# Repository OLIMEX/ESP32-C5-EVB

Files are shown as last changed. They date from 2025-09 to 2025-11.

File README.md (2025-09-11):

# ESP32-C5-EVB
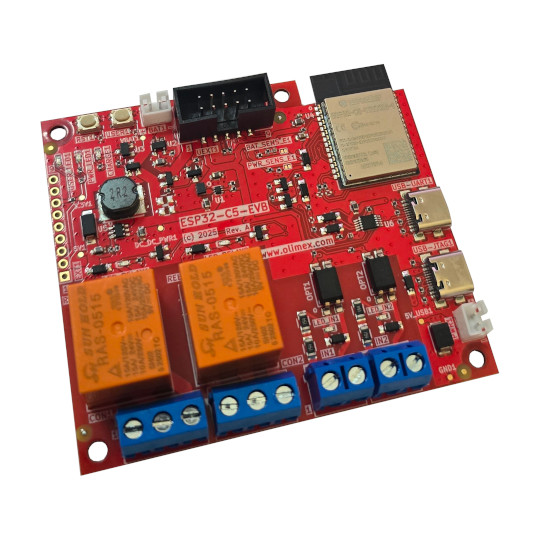
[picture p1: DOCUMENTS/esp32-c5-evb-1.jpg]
esp32-c5-evb-1


Development board for dual band 2.4G and 5Ghz WiFi 6, Bluetooth 5 LE, Zigbee, Thread, Matter development board with Relays, optoisolated inputs and LiPo battery UPS

https://www.olimex.com/Products/IoT/ESP32-C5/ESP32-C5-EVB/open-source-hardware

## Licensee
* Hardware is released under CERN Open Hardware Licence Version 2 - Strongly Reciprocal
* SOFTWARE is released under MIT Licensee
* Documentation is released under CC BY-SA 4.0

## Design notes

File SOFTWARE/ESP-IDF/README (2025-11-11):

# esp32-c5-evb-blinking-LED - esp-idf project
# After power-on the user led flashes 3 times, then blinks every second

#
# How to build the project:
#

# 1. Download esp-idf master branch or tag v5.5.1 (this project has been built with v5.5.1 tag)

git clone https://github.com/espressif/esp-idf.git

# OR

git clone https://github.com/espressif/esp-idf.git -b "v5.5.1"

# 2. Install esp-idf (do this one time only)
# 2.1 Go to esp-idf dir:

cd esp-idf

# 2.2 Run installation script. This will download and install all dependencies

./install.sh

# 3. Export esp-idf to PATH (you must do this every time, when you open terminal)
# 3.1 go to the esp-idf path:

cd PATH_TO_ESP-IDF/esp-idf

# 3.2 Execute the following command as it is, including the . symbol
. ./export.sh

# 3.3 go to the project directory
cd PATH/esp32-c5-evb-blinking-LED

# 4. Set target to esp32-c5 (one time only)

idf.py set-target esp32c5

# OPTIONAL: Change  sdkconfig  settings

idf.py menuconfig

# Build:

idf.py build

# Flash (change PORT with the actual port, related to ESP32-C5-EVB)
idf.py flash -p PORT

If everything is done after uploading the project, the led will flash 3 times, then blink every second.

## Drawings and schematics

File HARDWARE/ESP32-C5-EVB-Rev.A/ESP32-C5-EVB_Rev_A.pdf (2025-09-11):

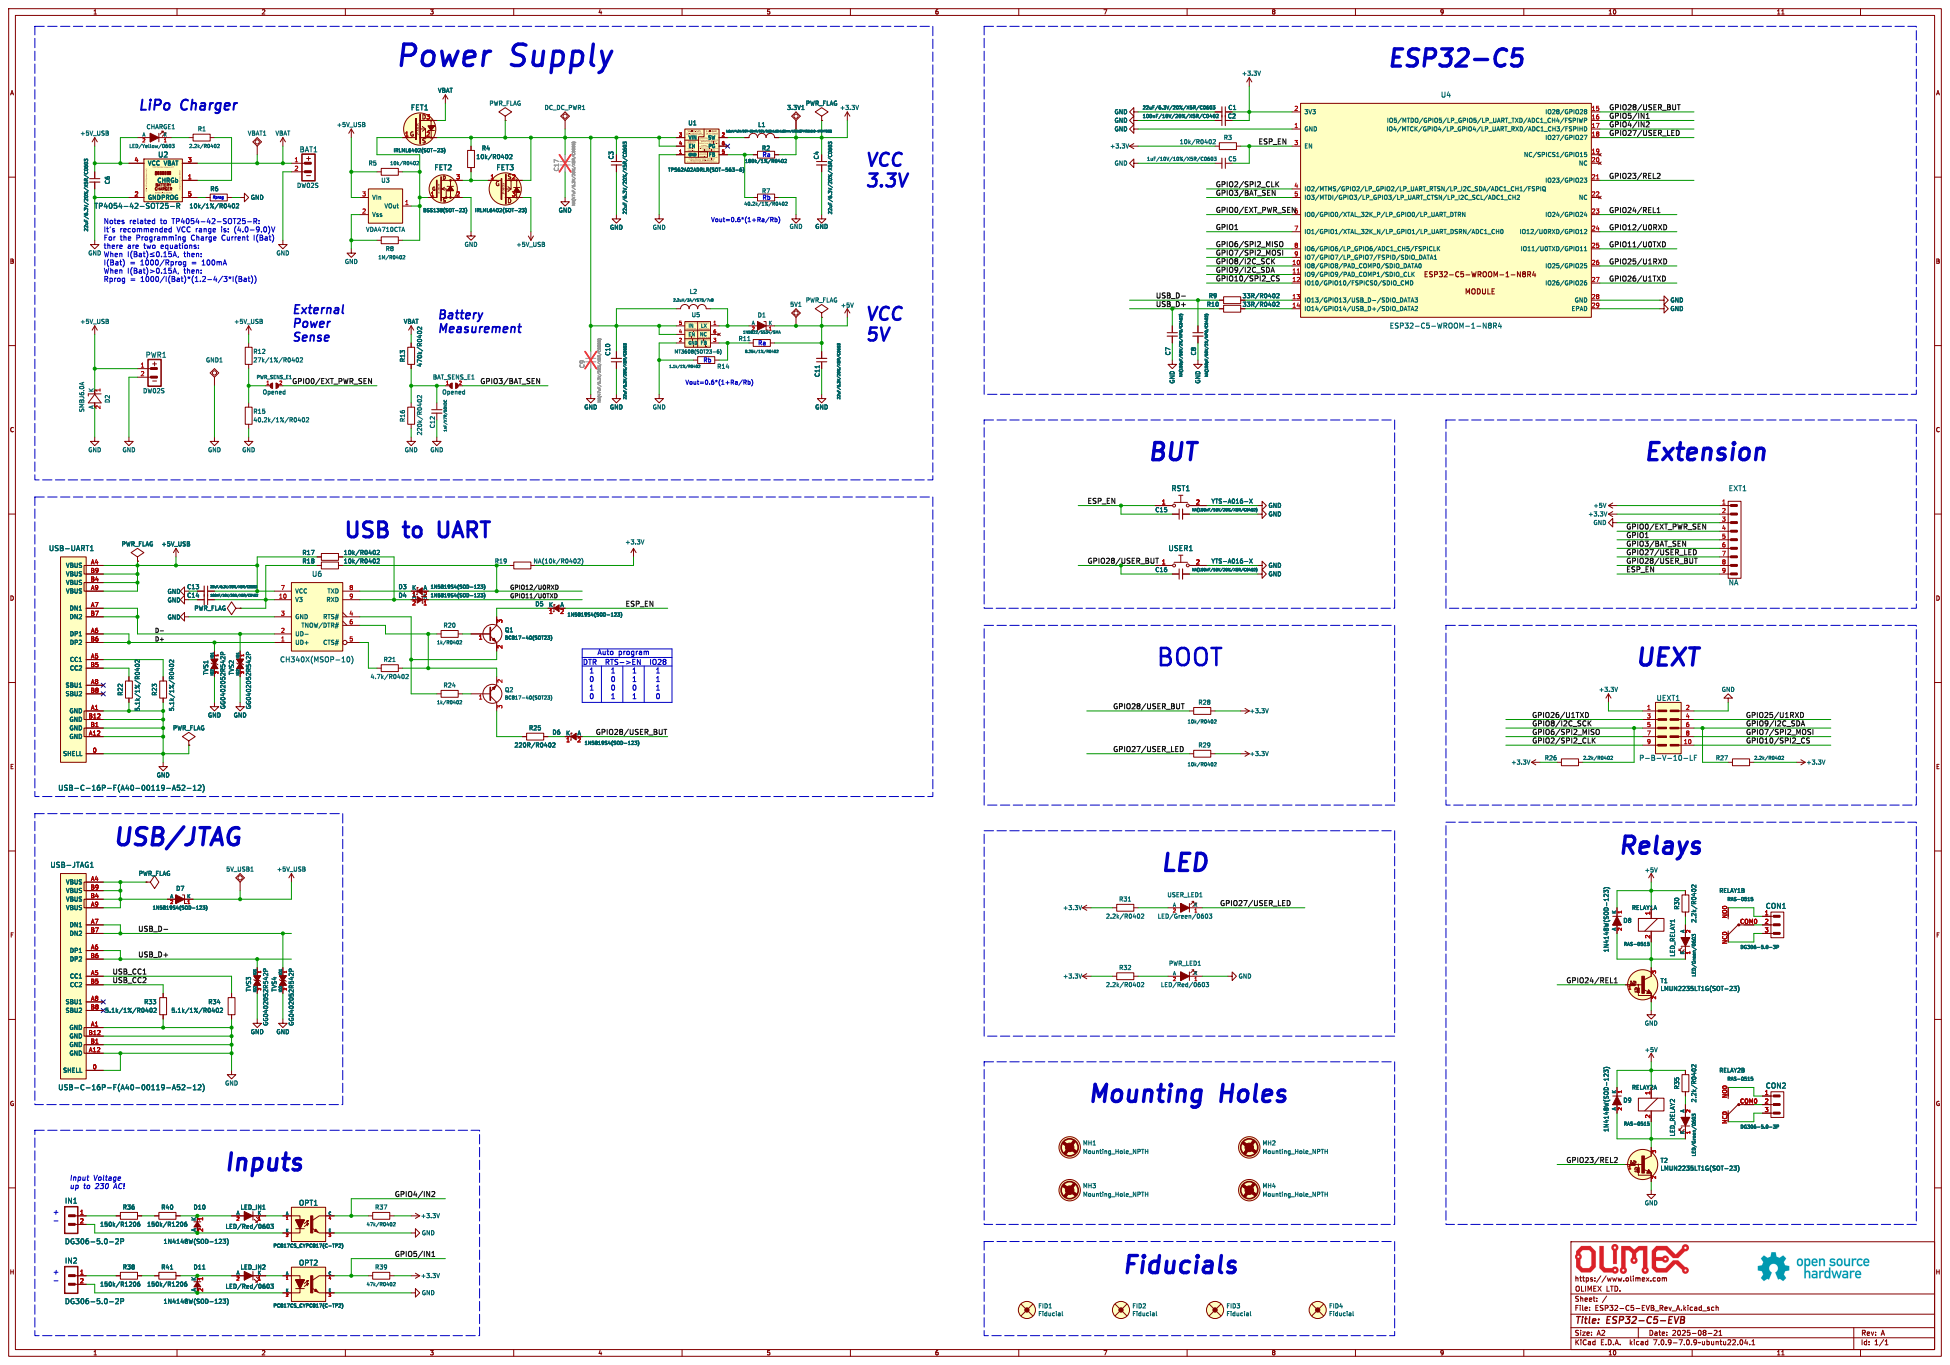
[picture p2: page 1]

In casea loweroutputrippleisdesired,higheroutputcapacitancecanhelpreducetheripple. Lx=1.0uH

Donotfloat. Enablecontrol. FB Input Current,I(FB)=100nA(max) FeedbackReferenceVoltage,V(REF)=0.6V
Rb mustnotbehigherthanþÿ100k© toprovideacceptablenoisesensitivity. ShutdownCurrentI(SHDN)=0.01-2uA

Cout=(10~22)uF/6.3V/X5Rþÿ(Vout"e1.8V). 22uFRecommended! Cout=22uF/6.3V/X5Rþÿ(1.2V"dVout<1.8V) Cout=44uF/6.3V/X5Rþÿ(0.6V"dVout<1.2V) DCR<50mR

Notes related to TP4054-42-SOT25-R:
there are two equations: When þÿI(Bat)"d0.15A, then:

Vout=0.6*(1+Rc/Rd) LX 1 GND
Current(Shutdown)=1uA(Max) FB InputBiasCurrent=-50nA(min) FB Voltage=0.6V(Typical) OperatingInputVoltage
QuiescentCurrent(PFM)=200uA(Max) QuiescentCurrent(PWM)=2.2mA(Max) RecommendedInductorvalues:up to 22uH.

because of its low forwardvoltagedropandfast reversesrecovery. V(ENH)=1.5V(Min)

V(ENL)=0.4V(Max) Vin=(2-24)VDC

The inductorshouldhavelow corelossat 1.2MHz andlow DCR for betterefficiency. RecommendedInput/OutputCapacitors: 22uF/X5R(X7R). Schottkydiodeis a goodchoicefor MT3608

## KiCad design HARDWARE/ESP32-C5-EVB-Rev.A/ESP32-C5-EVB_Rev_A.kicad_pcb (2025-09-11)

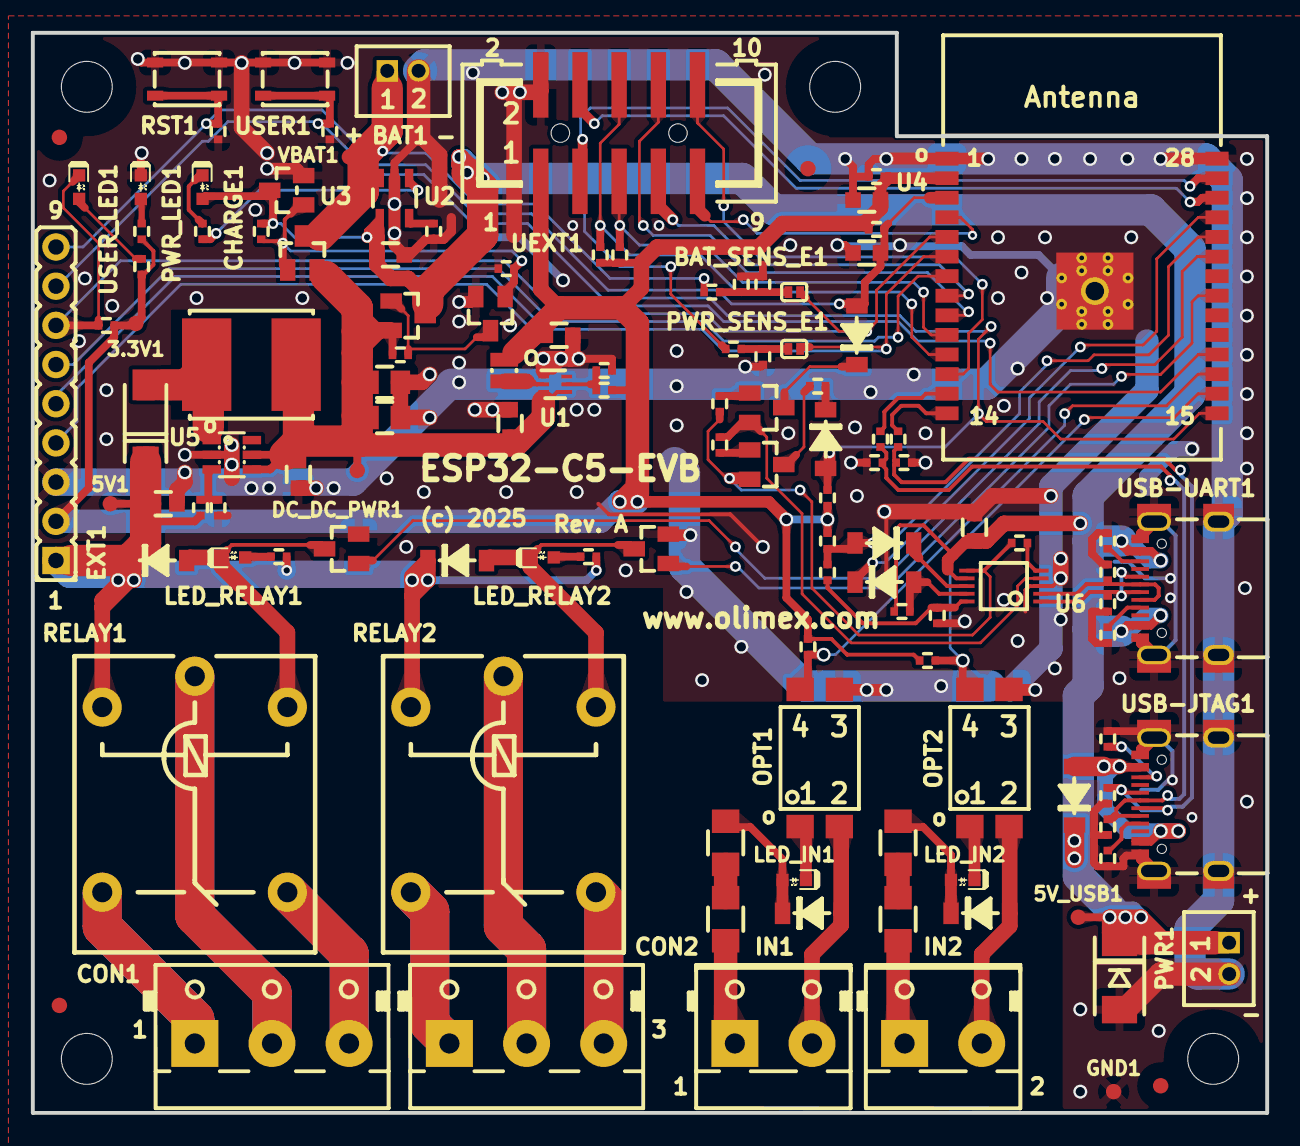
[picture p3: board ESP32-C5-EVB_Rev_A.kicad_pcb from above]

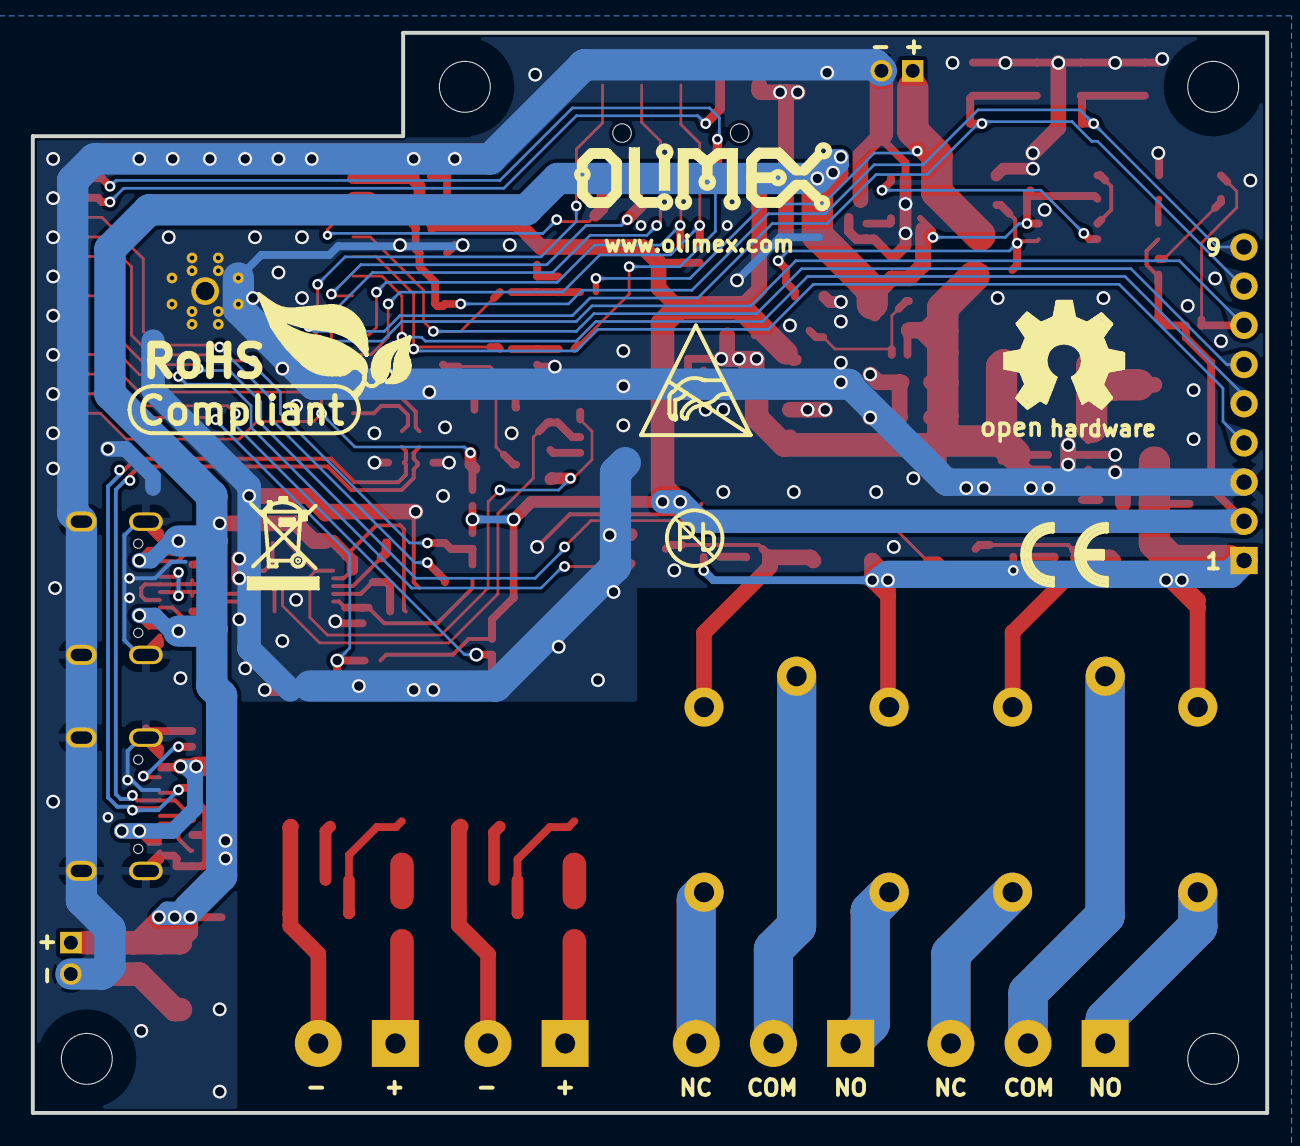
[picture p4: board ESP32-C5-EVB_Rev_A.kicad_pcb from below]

Board: 2 copper layers, 80.0 x 70.0 mm, 134 parts (7 on the bottom side), 81 nets.

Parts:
3.3V1, 5V1, 5V_USB1: TESTPAD; TESTPAD_40-ROUND
BAT1: DW02S; LIPO_BAT_VERTICAL_DW02S
BAT_SENS_E1: Opened; SJ_1_SMALLER
C1, C3, C4, C6, C10, C11, C13: 22uF/6.3V/20%/X5R/C0603; C_0603_5MIL_DWS
C2, C14: 100nF/10V/20%/X5R/C0402; C_0402_5MIL_DWS
C5: 1uF/10V/10%/X5R/C0603; C_0603_5MIL_DWS
C7, C8: NA(150pF/50V/2%/NP0/C0402); C_0402_5MIL_DWS
C9, C17: NA(47uF/6.3V/20%/X5R/C0805); C_0805_5MIL_DWS
C12: 1nF/X7R/50VDC; C_0402_5MIL_DWS
C15, C16: NA(100nF/10V/20%/X5R/C0402); C_0402_5MIL_DWS
CHARGE1: LED/Yellow/0603; LED_0603_KA
CON1, CON2: DG306-5.0-3P; TB3-DG306-5.0_3P
D1: 1N5822/SS34/SMA; SMA-KA
D2: SMBJ6.0A; DO214AA_1(K)-2(A)
D3, D4, D5, D6, D7: 1N5819S4(SOD-123); SOD-123_1C-2A_KA
D8, D9, D10, D11: 1N4148W(SOD-123); SOD-123_1C-2A_KA
DC_DC_PWR1: TESTPAD; TESTPAD_40-ROUND
EXT1: NA; HN1x9
FET1, FET3: IRLML6402(SOT-23); SOT23
FET2: BSS138(SOT-23); SOT23
FID1, FID2: Fiducial; Fiducial1x3
FID3, FID4: Fiducial; Fiducial1x3_Paste
GND1: TESTPAD; TESTPAD_40-ROUND
IN1, IN2: DG306-5.0-2P; TB2-DG306-5.0_2P
L1: 1.0uH/4.2A/DCR=35mR/20%/2.00x1.60x1.00mm/L2016(PI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; L_2016_MM
L2: 2.2uH/3A/YS75/7x8; YS75_7X8MM
LED_IN1, LED_IN2: LED/Red/0603; LED_0603_KA
LED_RELAY1, LED_RELAY2: LED/Green/0603; LED_0603_KA
Logo_OLIMEX_TB: Logo_OLIMEX_TB
MH1, MH2, MH3, MH4: Mounting_Hole_NPTH; Mounting_hole_3.3mm
OPT1, OPT2: PC817CS_CYPC817(C-TP2); H11A817C_SMD(PC817X3NIP06)_FP
PWR1: DW02S; LIPO_BAT_VERTICAL_DW02S
PWR_LED1: LED/Red/0603; LED_0603_KA
PWR_SENS_E1: Opened; SJ_1_SMALLER
Q1, Q2: BC817-40(SOT23); SOT23
R1, R26, R27, R30, R31, R32, R35: 2.2k/R0402; R_0402_5MIL_DWS
R2: 180k/1%/R0402; R_0402_5MIL_DWS
R3, R4, R5, R17, R18, R28, R29: 10k/R0402; R_0402_5MIL_DWS
R6: 10k/1%/R0402; R_0402_5MIL_DWS
R7, R15: 40.2k/1%/R0402; R_0402_5MIL_DWS
R8: 1M/R0402; R_0402_5MIL_DWS
R9, R10: 33R/R0402; R_0402_5MIL_DWS
R11: 8.25k/1%/R0402; R_0402_5MIL_DWS
R12: 27k/1%/R0402; R_0402_5MIL_DWS
R13: 470k/R0402; R_0402_5MIL_DWS
R14: 1.1k/1%/R0402; R_0402_5MIL_DWS
R16: 220k/R0402; R_0402_5MIL_DWS
R19: NA(10k/R0402); R_0402_5MIL_DWS
R20, R24: 1k/R0402; R_0402_5MIL_DWS
R21: 4.7k/R0402; R_0402_5MIL_DWS
R22, R23, R33, R34: 5.1k/1%/R0402; R_0402_5MIL_DWS
R25: 220R/R0402; R_0402_5MIL_DWS
R36, R38, R40, R41: 150k/R1206; R_1206_5MIL_DWS
R37, R39: 47k/R0402; R_0402_5MIL_DWS
RELAY1, RELAY2: RAS-0515; Relay_RAS-05-15_DrillSlot
RST1: YTS-A016-X
Sign_Antistatic: Sign_Antistatic
Sign_CE: CE_Sign
Sign_OSHW_8x8: Sign_OSHW_8x8
Sign_PB-Free: Sign_PB-Free
Sign_RecycleBin_1: Sign_RecycleBin_1
Sign_RoHS_1: Sign_RoHS_1
T1, T2: LMUN2235LT1G(SOT-23); SOT23
TVS1, TVS2, TVS3, TVS4: GG0402052R542P; D_0402_5MIL_DWS
U1: TPS62A02ADRLR(SOT-563-6); SOT-563-6
U2: TP4054-42-SOT25-R; SOT-23-5
U3: VDA4710CTA; SOT-23
U4: ESP32-C5-WROOM-1-N8R4; ESP32-C5-WROOM-1-N**4-UNIVERSAL_MODULE
U5: MT3608(SOT23-6); SOT23-6
U6: CH340X(MSOP-10); MSOP-10_Pitch-0.5mm_3.00x3.00x1.00mm
UEXT1: P-B-V-10-LF; GBH-254-SMT-10
USB-JTAG1: USB-C-16P-F(A40-00119-A52-12); USB2.0_TYPE-C(A40-00119-A52-12)_Paste
USB-UART1: USB-C-16P-F(A40-00119-A52-12); USB2.0_TYPE-C(A40-00119-A52-12)_Paste
USER1: YTS-A016-X
USER_LED1: LED/Green/0603; LED_0603_KA
VBAT1: TESTPAD; TESTPAD_40-ROUND

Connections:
+3.3V: 3.3V1.1 (Pad), C1.1, C2.2, C4.1, EXT1.2, L1.2, R2.2, R3.1, R19.2, R26.1, R27.2, R28.2, R29.2, R31.1, R32.1, R37.2, R39.2, U4.2 (3V3), UEXT1.1
+5V: 5V1.1 (Pad), C11.2, D1.1 (K), D8.1 (K), D9.1 (K), EXT1.1, R11.1, R30.2, R35.2, RELAY1.1, RELAY2.1
+5V_USB: 5V_USB1.1 (Pad), C6.1, C13.1, CHARGE1.2 (A), D2.1 (K), D7.1 (K), FET3.3, PWR1.1, R5.2, R12.1, R17.1, U2.4 (VCC), U3.3 (VIn), U6.7 (VCC), USB-UART1.A4 (VBUS), USB-UART1.A9 (VBUS), USB-UART1.B4 (VBUS), USB-UART1.B9 (VBUS)
/D+: TVS1.1 (IO1), U6.1 (UD+), USB-UART1.A6 (DP1), USB-UART1.B6 (DP2)
/D-: TVS2.1 (IO1), U6.2 (UD-), USB-UART1.A7 (DN1), USB-UART1.B7 (DN2)
/ESP_EN: C5.1, C15.1, D5.2 (A), EXT1.9, R3.2, RST1.1, U4.3 (EN)
/GPIO0/EXT_PWR_SEN: EXT1.4, PWR_SENS_E1.2, U4.6 (IO0/GPIO0/XTAL_32K_P/LP_GPIO0/LP_UART_D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)
/GPIO1: EXT1.5, U4.7 (IO1/GPIO1/XTAL_32K_N/LP_GPIO1/LP_UART_D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)
/GPIO2/SPI2_CLK: U4.4 (IO2/MTMS/GPIO2/LP_GPIO2/LP_UART_RTSN/LP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), UEXT1.9
/GPIO3/BAT_SEN: BAT_SENS_E1.2, EXT1.6, U4.5 (IO3/MTDI/GPIO3/LP_GPIO3/LP_UART_CTSN/LP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)
/GPIO4/IN2: OPT1.4 (C), R37.1, U4.17 (IO4/MTCK/GPIO4/LP_GPIO4/LP_UART_RXD/ADC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)
/GPIO5/IN1: OPT2.4 (C), R39.1, U4.16 (IO5/MTDO/GPIO5/LP_GPIO5/LP_UART_TXD/ADC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)
/GPIO6/SPI2_MISO: U4.8 (IO6/GPIO6/LP_GPIO6/ADC1_CH5/FSPICLK), UEXT1.7
/GPIO7/SPI2_MOSI: U4.9 (IO7/GPIO7/LP_GPIO7/FSPID/SDIO_DATA1), UEXT1.8
/GPIO8/I2C_SCK: R26.2, U4.10 (IO8/GPIO8/PAD_COMP0/SDIO_DATA0), UEXT1.5
/GPIO9/I2C_SDA: R27.1, U4.11 (IO9/GPIO9/PAD_COMP1/SDIO_CLK), UEXT1.6
/GPIO10/SPI2_CS: U4.12 (IO10/GPIO10/FSPICS0/SDIO_CMD), UEXT1.10
/GPIO11/U0TXD: D4.1 (K), U4.25 (IO11/U0TXD/GPIO11)
/GPIO12/U0RXD: D3.2 (A), R18.2, R19.1, U4.24 (IO12/U0RXD/GPIO12)
/GPIO23/REL2: T2.1 (B), U4.21 (IO23/GPIO23)
/GPIO24/REL1: T1.1 (B), U4.23 (IO24/GPIO24)
/GPIO25/U1RXD: U4.26 (IO25/GPIO25), UEXT1.4
/GPIO26/U1TXD: U4.27 (IO26/GPIO26), UEXT1.3
/GPIO27/USER_LED: EXT1.7, R29.1, U4.18 (IO27/GPIO27), USER_LED1.1 (K)
/GPIO28/USER_BUT: C16.1, D6.2 (A), EXT1.8, R28.1, U4.15 (IO28/GPIO28), USER1.1
/USB_CC1: R34.2, USB-JTAG1.A5 (CC1)
/USB_CC2: R33.2, USB-JTAG1.B5 (CC2)
/USB_D+: C7.1, R10.2, TVS3.1 (IO1), USB-JTAG1.A6 (DP1), USB-JTAG1.B6 (DP2)
/USB_D-: C8.1, R9.1, TVS4.1 (IO1), USB-JTAG1.A7 (DN1), USB-JTAG1.B7 (DN2)
GND: BAT1.2, C1.2, C2.1, C3.2, C4.2, C5.2, C6.2, C7.2, C8.2, C9.2, C10.1, C11.1, C12.2, C13.2, C14.2, C15.2, C16.2, C17.2, D2.2 (A), EXT1.3, FET2.2 (S), GND1.1 (Pad), OPT1.3 (E), OPT2.3 (E), PWR1.2, PWR_LED1.1 (K), R6.1, R7.2, R8.2, R14.2, R15.2, R16.2, R22.1, R23.1, R33.1, R34.1, RST1.2, T1.2 (E), T2.2 (E), TVS1.2 (IO2), TVS2.2 (IO2), TVS3.2 (IO2), TVS4.2 (IO2), U1.1 (GND), U2.2 (GND), U3.2 (Vss), U4.1 (GND), U4.28 (GND), U4.29 (EPAD), U5.2 (GND), U6.3 (GND), UEXT1.2, USB-JTAG1.0 (SHELL), USB-JTAG1.A1 (GND), USB-JTAG1.A12 (GND), USB-JTAG1.B1 (GND), USB-JTAG1.B12 (GND), USB-UART1.0 (SHELL), USB-UART1.A1 (GND), USB-UART1.A12 (GND), USB-UART1.B1 (GND), USB-UART1.B12 (GND), USER1.2
unnamed: BAT_SENS_E1.1, C12.1, R13.2, R16.1
unnamed: CHARGE1.1 (K), R1.1
unnamed: CON1.1, RELAY1.NO0
unnamed: CON1.2, RELAY1.COM0
unnamed: CON1.3, RELAY1.NC0
unnamed: CON2.1, RELAY2.NO0
unnamed: CON2.2, RELAY2.COM0
unnamed: CON2.3, RELAY2.NC0
unnamed: D1.2 (A), L2.2, U5.1 (LX)
unnamed: D3.1 (K), U6.8 (TXD)
unnamed: D4.2 (A), R17.2, U6.9 (RXD)
unnamed: D5.1 (K), Q1.3 (C)
unnamed: D6.1 (K), R25.2
unnamed: D7.2 (A), USB-JTAG1.A4 (VBUS), USB-JTAG1.A9 (VBUS), USB-JTAG1.B4 (VBUS), USB-JTAG1.B9 (VBUS)
unnamed: D8.2 (A), LED_RELAY1.1 (K), RELAY1.2, T1.3 (C)
unnamed: D9.2 (A), LED_RELAY2.1 (K), RELAY2.2, T2.3 (C)
unnamed: D10.2 (A), IN1.2, OPT1.2 (K)
unnamed: D10.1 (K), LED_IN1.2 (A), R40.2
unnamed: D11.2 (A), IN2.2, OPT2.2 (K)
unnamed: D11.1 (K), LED_IN2.2 (A), R41.2
unnamed: FET2.3 (D), FET3.1, R4.1
unnamed: FET1.1, FET2.1 (G), R5.1, R8.1, U3.1 (VOut)
unnamed: IN1.1, R36.1
unnamed: IN2.1, R38.1
unnamed: LED_IN1.1 (K), OPT1.1 (A)
unnamed: LED_IN2.1 (K), OPT2.1 (A)
unnamed: LED_RELAY1.2 (A), R30.1
unnamed: LED_RELAY2.2 (A), R35.1
unnamed: PWR_LED1.2 (A), R32.2
unnamed: PWR_SENS_E1.1, R12.2, R15.1
unnamed: Q1.1 (B), R20.2
unnamed: Q1.2 (E), R24.1, U6.4 (RTS#)
unnamed: Q2.1 (B), R24.2
unnamed: Q2.3 (C), R25.1
unnamed: Q2.2 (E), R20.1, R21.1, U6.6 (TNOW/DTR#)
unnamed: R36.2, R40.1
unnamed: R38.2, R41.1
unnamed: C3.1, C9.1, C10.2, C17.1, DC_DC_PWR1.1 (Pad), FET1.2, FET3.2, L2.1, R4.2, U1.3 (VIN), U1.4 (EN), U5.4 (EN), U5.5 (IN)
unnamed: R2.1, R7.1, U1.5 (FB)
unnamed: L1.1, U1.2 (SW)
unnamed: R1.2, U2.1 (CHRGb)
unnamed: R6.2, U2.5 (PROG)
unnamed: R9.2, U4.13 (IO13/GPIO13/USB_D-/SDIO_DATA3)
unnamed: R10.1, U4.14 (IO14/GPIO14/USB_D+/SDIO_DATA2)
unnamed: R11.2, R14.1, U5.3 (FB)
unnamed: R21.2, U6.5 (CTS#)
unnamed: C14.1, R18.1, U6.10 (V3)
unnamed: R23.2, USB-UART1.A5 (CC1)
unnamed: R22.2, USB-UART1.B5 (CC2)
unnamed: R31.2, USER_LED1.2 (A)
VBAT: BAT1.1, FET1.3, R13.1, U2.3 (VBAT), VBAT1.1 (Pad)

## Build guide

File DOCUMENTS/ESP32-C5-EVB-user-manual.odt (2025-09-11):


ESP32-C5-EVB

User Manual

Rev.1.0 September 2025 olimex.com

# What is ESP32-C5-EVB

ESP32-C5-EVB (https://www.olimex.com/Products/IoT/ESP32-C5/ESP32-C5-EVB/open-source-hardware) is Dual band 2.4Ghz and 5Ghz WiFi 6, Bluetooth 5 LE, Zigbee, Thread, Matter development board with Relays, optoisolated inputs and LiPo battery UPS. The board is equiped with ESP32-C5-WROOM-N8R4 module with 8MB of Flash and 4MB of RAM

The features of ESP32-C5-EVB (https://www.olimex.com/Products/IoT/ESP32-C5/ESP32-C5-EVB/open-source-hardware) are:

- ESP32-C5-WROOM-N8R4 module
- 32 bit RISC-V processor 240Mhz
- Dual-Band Wi-Fi (2.4 GHz + 5 GHz)
- Bluetooth 5, Zigbee, Thread, Matter
- 8 MB Flash + 4 MB RAM
- Two relays – rated 250V / 10A
- Two opto-isolated inputs
- UEXT connector
- USB-C (Power & Debug)
- USB-C JTAG
- Boot & Reset buttons
- Extension connector
- LiPo UPS charger & step-up converter
- Three mouting holes
- Dimensions 80x70mm
  ESP32-C5-EVB (https://www.olimex.com/Products/IoT/ESP32-C5/ESP32-C5-EVB/open-source-hardware) is Open Source Hardware, all CAD files and firmware and available, so people can study and modify.

+ Important notice: If ESP32-C5-EVB (https://www.olimex.com/Products/IoT/ESP32-C5/ESP32-C5-EVB/open-source-hardware) is not mounted in box be careful to not place it on metal surface, nor drop metal objects on top of the PCB! This will lead to damage.

## Order codes for ESP32-C5-EVB and accessories:

ESP32-C5-EVB (https://www.olimex.com/Products/IoT/ESP32-C5/ESP32-C5-EVB/open-source-hardware) ESP32-C5-EVB development board

BOX-ESP32-C5-EVB Plastic box for ESP32-C5-EVB

USB-CABLE-AM-USB3-C (https://www.olimex.com/Products/Components/Cables/USB-CABLE-AM-USB3-C/) High speed, High current cable for power supply and programming

UEXT modules (https://www.olimex.com/Products/Modules/) many UEXT modules which can connect to UEXT connector

BATTERY-LiPo (https://www.olimex.com/Products/Power-Supply/Lipo-battery/BATTERY-LIPO1400mAh/)1400mAh (https://www.olimex.com/Products/Power-Supply/Lipo-battery/BATTERY-LIPO1400mAh/) LiPo battery compatible with ESP32-C5-EVB (https://www.olimex.com/Products/IoT/ESP32-C5/ESP32-C5-EVB/open-source-hardware)

BATTERY-CABLE (https://www.olimex.com/Products/Components/Cables/BATTERY-CABLE/) JST2.0 cable can be used for external power supply +5V on PWR1 connector instead to power via USB-C

(https://www.olimex.com/Products/Components/Cables/USB-CABLE-AM-USB3-C/)

# HARDWARE

## ESP32-C5-EVB layout:

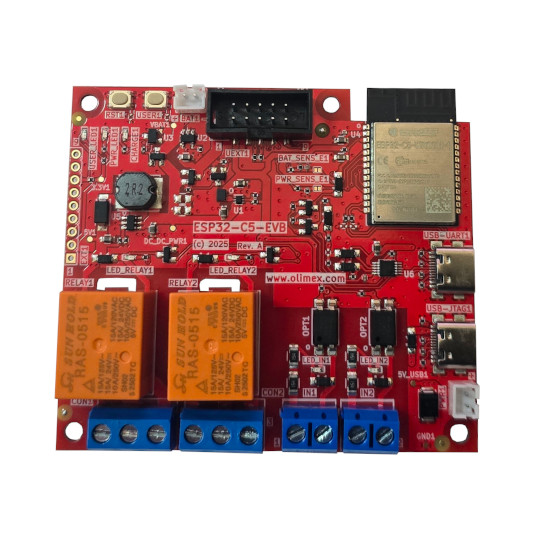
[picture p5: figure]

ESP32-C5-WROOM-N8R4

Power USB-C

Debug UART

Power USB-C JTAG

POWER SUPPLY

UEXT

EXT connector

RELAY1

RELAY1 status LED

RELAY2

RELAY2 status LED

UPS LiPo battery

USER button

RESET button

INPUT1 status LED

INPUT1

INPUT2

INPUT2 status LED

USER LED

POWER LED

CHARGE LED

## Power supply:

ESP32-C5-EVB (https://www.olimex.com/Products/IoT/ESP32-C5/ESP32-C5-EVB/open-source-hardware) can be powered from several sources:

USB-UART1 – this is USB-C connector with USB to serial convertor attached. It works as debug UART and can be used for programming with esptoo.py with automatic bootloader mode invoke.

USB-JTAG1 – this is USB-C connector connected directly to ESP32-C5 JTAG ports.

PWR1 – this is JST2.0 connector compatible with BATTERY-CABLE (https://www.olimex.com/Products/Components/Cables/BATTERY-CABLE/) . This is reliable connection for industrial solutions, as USB-C cable connection can be easily pulled out and it’s great for development but not in more demanding environments.

+ Important notice: Never connect more than 5V on PWR1!This will damage the board

+ Important notice: The USB-C VCC is directly connected to PWR1 +5V so you should not apply external power supply to PWR1 connector while you are connected to USB-C connector, or there is risk to damage your USB-host.

LiPo battery – ESP32-C5-EVB (https://www.olimex.com/Products/IoT/ESP32-C5/ESP32-C5-EVB/open-source-hardware) have smart switching between the different power supplies and LiPO charger, so when USB-C and PWR1 external power supply is missing LiPo battery with Step-Up connector is used to keep all ESP32-C5-EVB (https://www.olimex.com/Products/IoT/ESP32-C5/ESP32-C5-EVB/open-source-hardware) functionality.

When working on LiPo battery there are provisions to sense if the board is powered by LiPo battery or external source with GPIO0 and the battery voltage with GPIO3. By default these are not connected so GPIO0 and GPIO3 can be used for other purpose, but SMT jumper can be shorten in case this functionality is necessary.

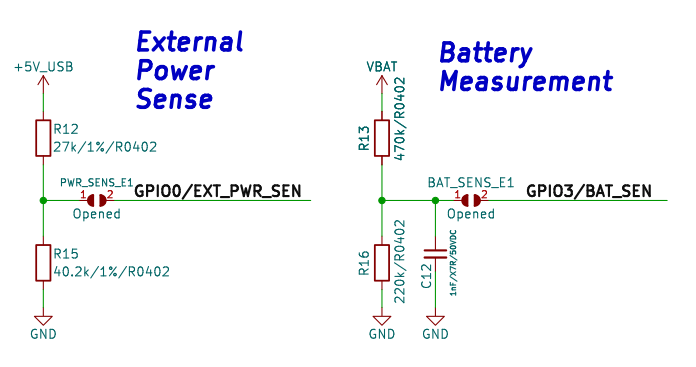
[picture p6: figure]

## UEXT connector:

UEXT connector stands for Universal EXTension connector and contain +3.3V, GND, I2C, SPI, UART signals.

UEXT connector can be in different shapes.

The original UEXT connector is 0.1” 2.54mm step boxed plastic connector. All signals are with 3.3V levels.

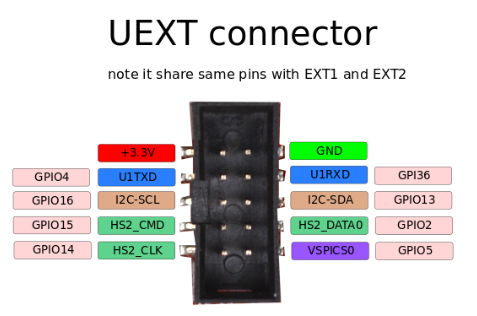
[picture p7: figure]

Olimex has developed number of MODULES (https://www.olimex.com/Products/Modules/) with this connector. There are temperature, humidity, pressure, magnetic field, light sensors. Modules with LCDs, LED matrix, Relays, Bluetooth, Zigbee, WiFi, GSM, GPS, RFID, RTC, EKG, sensors and etc.

## ESP32-C5-EVB UEXT connector:

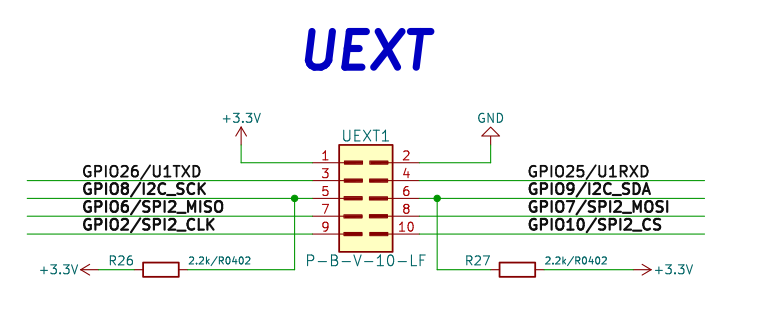
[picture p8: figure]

## EXT1 connector signals:

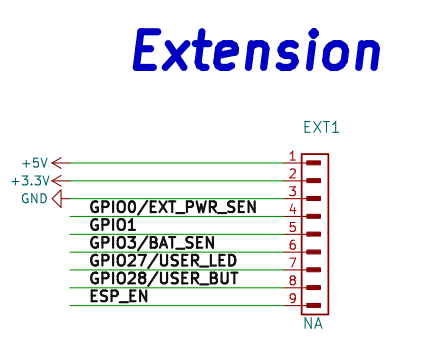
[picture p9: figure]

## Digital High Voltage Inputs:

GPIO4 and GPIO5 are connected to terminal blocks via opto insulators with status LEDs.

These inputs are very useful when you want for instance to measure the time machine is ON – you connect directly to the machine power line. When the machine is powered the corresponding GPIO port will become LOW. When the machine not work it will be HIGH.

When AC or DC voltage is applied between IN1 terminals RED status LED will switch ON and GPIO4 will be LOW, when no voltage is present the LED is off and GPIO4 is in HIGH state.

When AC or DC voltage is applied between IN2 terminals RED status LED will switch ON and GPIO5 will be LOW, when no voltage is present the LED is off and GPIO5 is in HIGH state.

The input voltage should be between 100 and 300VDC or 120-220VAC when DC voltage is applied you should mind the + and – marking on the connectors.

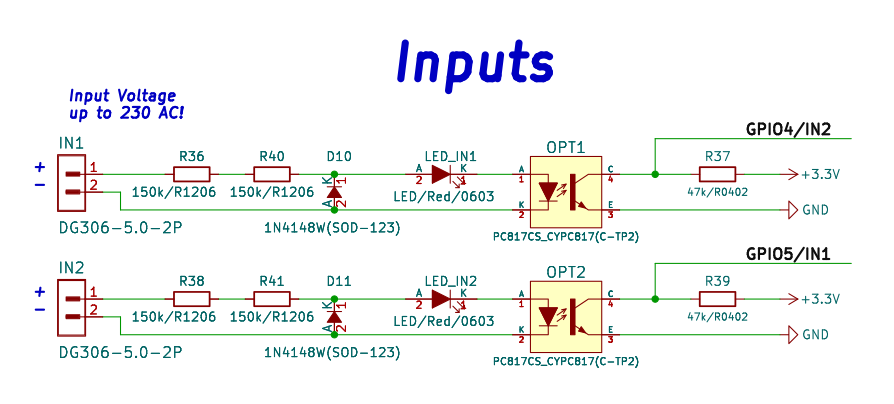
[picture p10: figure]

## RELAY outputs:

GPIO23 and GPIO24 drive RELAY1 and RELAY2. When HIGH level is assigned to these ports, the RELAY and the GREEN status LED are switched ON and the relay contacts NO-COM are closed, NC-COM opened.

When GPIO23 and GPIO24 have LOW level the RELAY and STATUS LED are OFF and NO-COM is opened, NC-COM is closed.

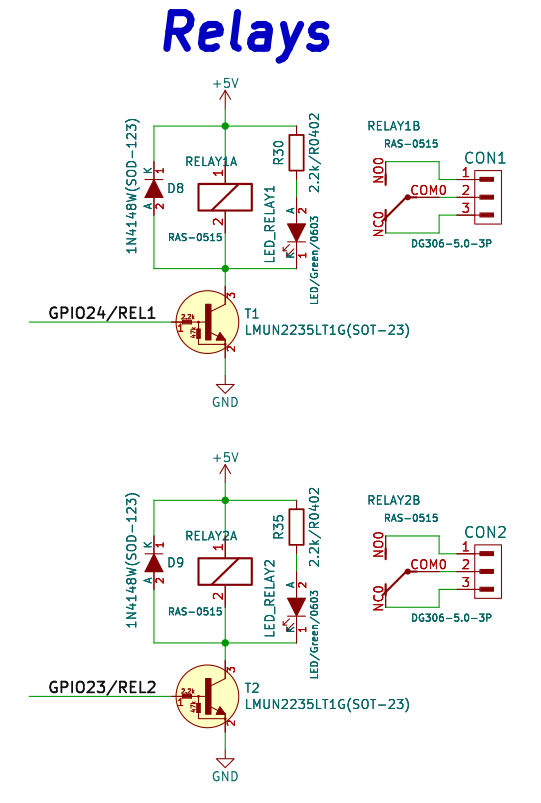
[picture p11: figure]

## LEDs:

GPIO27 is connected to GREEN user LED, when the level is LOW LED is ON, when the level is HIGH the LED is OFF.

RED power LED is ON when the board is powered.

YELLOW LED for CHARGING status: OFF – battery is fully charged, ON – battery is charging, Blink – No battery.

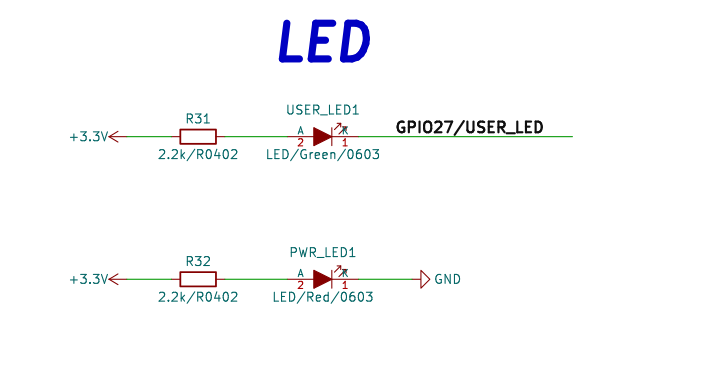
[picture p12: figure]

GREEN RELAY status LED – ON relay is energized, OFF relay is not powered.

RED input status LED – ON when voltage is present, OFF when no voltage on the input.

## ESP32-C5-EVB schematics:

ESP32-C5-E (https://www.olimex.com/Products/IoT/ESP32-C5/ESP32-C5-EVB/open-source-hardware)VB (https://www.olimex.com/Products/IoT/ESP32-C5/ESP32-C5-EVB/open-source-hardware) latest schematic is on GitHub (https://github.com/OLIMEX/ESP32-C5-EVB)

# SOFTWARE:

ESP32-C5-E (https://www.olimex.com/Products/IoT/ESP32-C5/ESP32-C5-EVB/open-source-hardware)VB (https://www.olimex.com/Products/IoT/ESP32-C5/ESP32-C5-EVB/open-source-hardware) can be programmed with Espressif IDF 5.5

(https://github.com/vsladkov/reload-emulator)

It’s very new board and Arduino, PlatformIO, MicroPython and ESPHome are still not supporting it.

# Revision History

Revision 1.0 September 2025

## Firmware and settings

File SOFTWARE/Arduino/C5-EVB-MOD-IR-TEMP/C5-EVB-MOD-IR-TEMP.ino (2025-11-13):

/*
  Olimex ESP32-C5-EVB + MOD-IR-TEMP (MLX90614) Demo
  ---------------------------------------------------------
  Demonstrates how to read infrared temperature data from the MLX90614
  connected via the UEXT port (I2C interface).

  Hardware connections (UEXT pinout):
    UEXT Pin 3 -> SDA  -> ESP32-C5 GPIO9
    UEXT Pin 4 -> SCL  -> ESP32-C5 GPIO8
    UEXT Pin 1 -> 3.3V (sensor power)
    UEXT Pin 2 -> GND  (ground)

  Requirements:
    - Arduino IDE with ESP32 board support installed
    - Adafruit MLX90614 library (install via Library Manager)
      → Tools > Manage Libraries > search "Adafruit MLX90614"
    - Board selected: "ESP32C5 Dev Module" 

  Functionality:
    - Initializes I2C communication on GPIO2/GPIO3
    - Reads ambient and object temperature every second
    - Prints results over USB serial
    
  Date: 2025-11-13
*/

#include <Wire.h>
#include <Adafruit_MLX90614.h>

// Create MLX90614 object
Adafruit_MLX90614 mlx = Adafruit_MLX90614();

// Define I2C pins for ESP32-C5-EVB (UEXT connector)
#define SDA_PIN 9
#define SCL_PIN 8

void setup() {
  // Start serial communication
  Serial.begin(115200);
  delay(1000);
  Serial.println("\n=== Olimex ESP32-C5-EVB + MOD-IR-TEMP (MLX90614) Demo ===");
  Serial.println("Initializing I2C and MLX90614 sensor...");

  // Initialize I2C on custom pins
  Wire.begin(SDA_PIN, SCL_PIN);

  // Initialize the MLX90614 sensor
  if (!mlx.begin()) {
    Serial.println("Error: MLX90614 not detected! Check wiring and power.");
    while (true) {
      delay(1000);
      Serial.println("Retrying...");
    }
  }

  Serial.println("MLX90614 detected successfully!");
  Serial.println("-----------------------------------------------------");
  Serial.println("Ambient and Object temperatures will be printed below:");
}

void loop() {
  // Read ambient temperature (air around the sensor)
  double ambientTemp = mlx.readAmbientTempC();

  // Read object temperature (measured by IR)
  double objectTemp = mlx.readObjectTempC();

  // Print to Serial Monitor
  Serial.print("Ambient: ");
  Serial.print(ambientTemp, 2);
  Serial.print(" °C   |   Object: ");
  Serial.print(objectTemp, 2);
  Serial.println(" °C");

  // Wait before next reading
  delay(1000);
}

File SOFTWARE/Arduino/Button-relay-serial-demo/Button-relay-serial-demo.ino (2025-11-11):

/*
  Olimex ESP32-C5-EVB Relay Demo with 4-step cycle
  =================================================
  Functionality:
    - USER1 button (GPIO28, active LOW) cycles through 4 relay states:
        0: Both relays OFF
        1: Relay1 ON, Relay2 OFF
        2: Relay1 OFF, Relay2 ON
        3: Both relays ON
        4: Back to 0 (repeat)
    - Relay1 -> GPIO24
    - Relay2 -> GPIO23
    - Relay states printed over USB-UART1 every 1 second

  Board Configuration:
    - In Arduino IDE select "ESP32C5 Dev Module"
    - Default clock and USB-UART1 (Serial) settings are fine
    - No extra libraries needed

  Hardware:
    - USER1 button: GPIO28, active LOW (internal pull-up used)
    - Relay1: GPIO24
    - Relay2: GPIO23
*/

const int buttonPin = 28;   // USER1 button
const int relay1Pin = 24;   // Relay 1
const int relay2Pin = 23;   // Relay 2

// Current step in 4-step cycle (0..3)
int relayStep = 0;

// For button debouncing
bool lastButtonState = HIGH;  // previous reading
bool buttonPressed = false;   // prevents multiple toggles on long press
unsigned long lastDebounceTime = 0;
const unsigned long debounceDelay = 50;

// For periodic printing
unsigned long lastPrintTime = 0;
const unsigned long printInterval = 1000; // 1 second

void setup() {
  Serial.begin(115200);  // USB-UART1

  pinMode(buttonPin, INPUT_PULLUP);  // USER1 button active LOW
  pinMode(relay1Pin, OUTPUT);
  pinMode(relay2Pin, OUTPUT);

  // Start with both relays OFF
  digitalWrite(relay1Pin, LOW);
  digitalWrite(relay2Pin, LOW);

  Serial.println("ESP32-C5 Relay Demo Started - 4-Step Cycle");
}

void loop() {
  // --- BUTTON HANDLING ---
  int reading = digitalRead(buttonPin);

  // Detect button state change for debouncing
  if (reading != lastButtonState) {
    lastDebounceTime = millis();
  }

  if ((millis() - lastDebounceTime) > debounceDelay) {
    // Detect button press (HIGH -> LOW transition)
    if (reading == LOW && !buttonPressed) {
      // Move to next step in cycle
      relayStep = (relayStep + 1) % 4;

      // Update relay states according to step
      switch (relayStep) {
        case 0:  // Both OFF
          digitalWrite(relay1Pin, LOW);
          digitalWrite(relay2Pin, LOW);
          break;
        case 1:  // Relay1 ON, Relay2 OFF
          digitalWrite(relay1Pin, HIGH);
          digitalWrite(relay2Pin, LOW);
          break;
        case 2:  // Relay1 OFF, Relay2 ON
          digitalWrite(relay1Pin, LOW);
          digitalWrite(relay2Pin, HIGH);
          break;
        case 3:  // Both ON
          digitalWrite(relay1Pin, HIGH);
          digitalWrite(relay2Pin, HIGH);
          break;
      }

      buttonPressed = true;  // mark as handled
    }

    // Reset buttonPressed when released
    if (reading == HIGH) {
      buttonPressed = false;
    }
  }

  lastButtonState = reading;

  // --- PERIODIC PRINTING ---
  if (millis() - lastPrintTime >= printInterval) {
    lastPrintTime = millis();
    printRelayStates();
  }
}

// Print current relay states to Serial
void printRelayStates() {
  Serial.print("Relay1: ");
  Serial.print(digitalRead(relay1Pin) ? "ON" : "OFF");
  Serial.print(" | Relay2: ");
  Serial.println(digitalRead(relay2Pin) ? "ON" : "OFF");
  Serial.print("Current step: ");
  Serial.println(relayStep);
}

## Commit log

2025-09-11 initial upload
    [ESP32-C5-EVB_Rev_A-B_Cu.gbr, ESP32-C5-EVB_Rev_A-B_Mask.gbr, ESP32-C5-EVB_Rev_A-B_Paste.gbr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]
2025-11-11 Update
    Added SOFTWARE demos for Arduino and ESP-IDF
2025-11-11 Update
    Relay demo for Arduino

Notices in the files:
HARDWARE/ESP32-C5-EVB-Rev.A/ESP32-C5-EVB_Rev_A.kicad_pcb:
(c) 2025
